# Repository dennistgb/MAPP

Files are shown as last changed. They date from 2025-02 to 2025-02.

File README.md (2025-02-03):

# Testing examples

You can test examples using the [htrun](https://github.com/ARMmbed/mbed-os-tools/tree/master/packages/mbed-host-tests) tool and templated print log.

To run the test, use this command after you build the example:

```
$ mbedhtrun -d <MOUNT_POINT> -p <SERIAL_PORT> -m <TARGET> -f ./BUILD/<TARGET>/<TOOLCHAIN>/mbed-os-example-blinky-baremetal.bin --compare-log tests/blinky-baremetal.log
```

For example:

```
mbedhtrun -d /Volumes/DAPLINK -p /dev/tty.usbmodem21102 -m K64F -f ./BUILD/K64F/GCC_ARM/mbed-os-example-blinky-baremetal.bin --compare-log tests/blinky-baremetal.log
```

To find your target `MOUNT_POINT` and `SERIAL_PORT`, please see [mbedls](https://github.com/ARMmbed/mbed-os-tools/blob/master/packages/mbed-ls/README.md#mbed-ls).

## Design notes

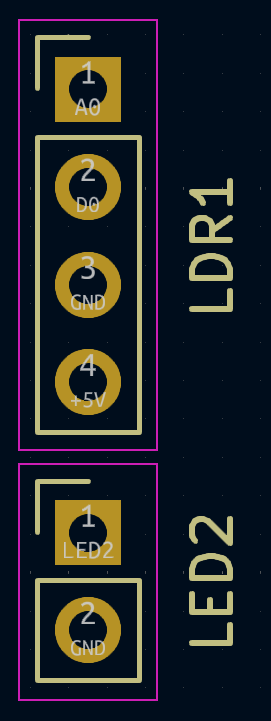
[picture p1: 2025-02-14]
images/pic2.png

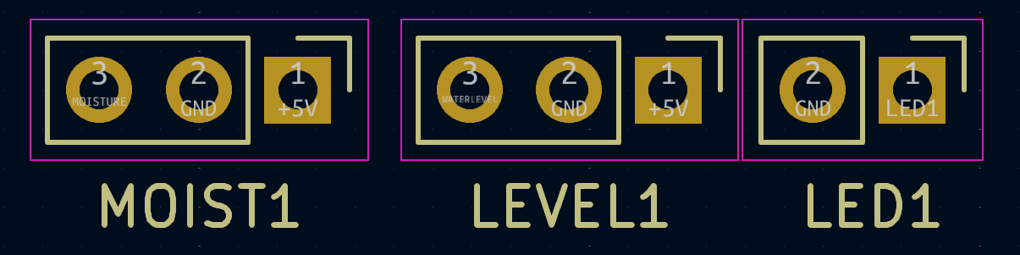
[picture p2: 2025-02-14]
images/pic1.png

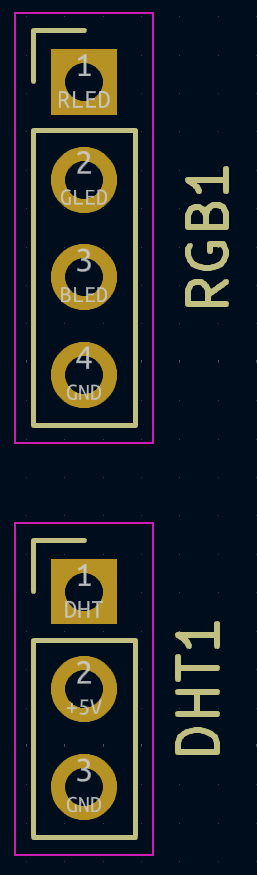
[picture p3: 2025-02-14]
images/pic3.png

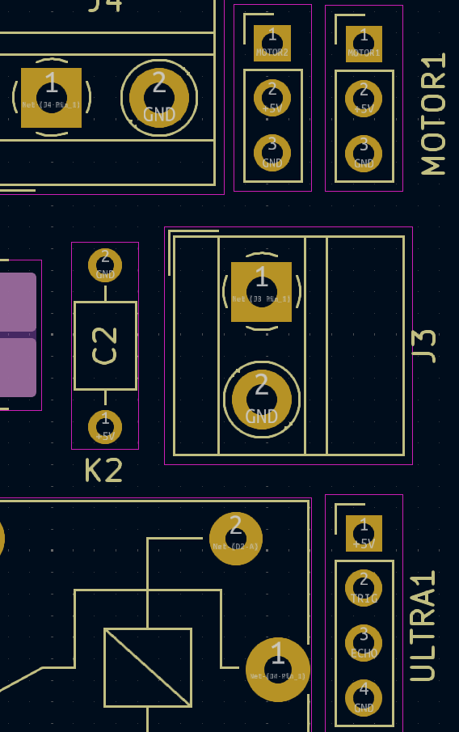
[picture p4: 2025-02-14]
images/pic4.png

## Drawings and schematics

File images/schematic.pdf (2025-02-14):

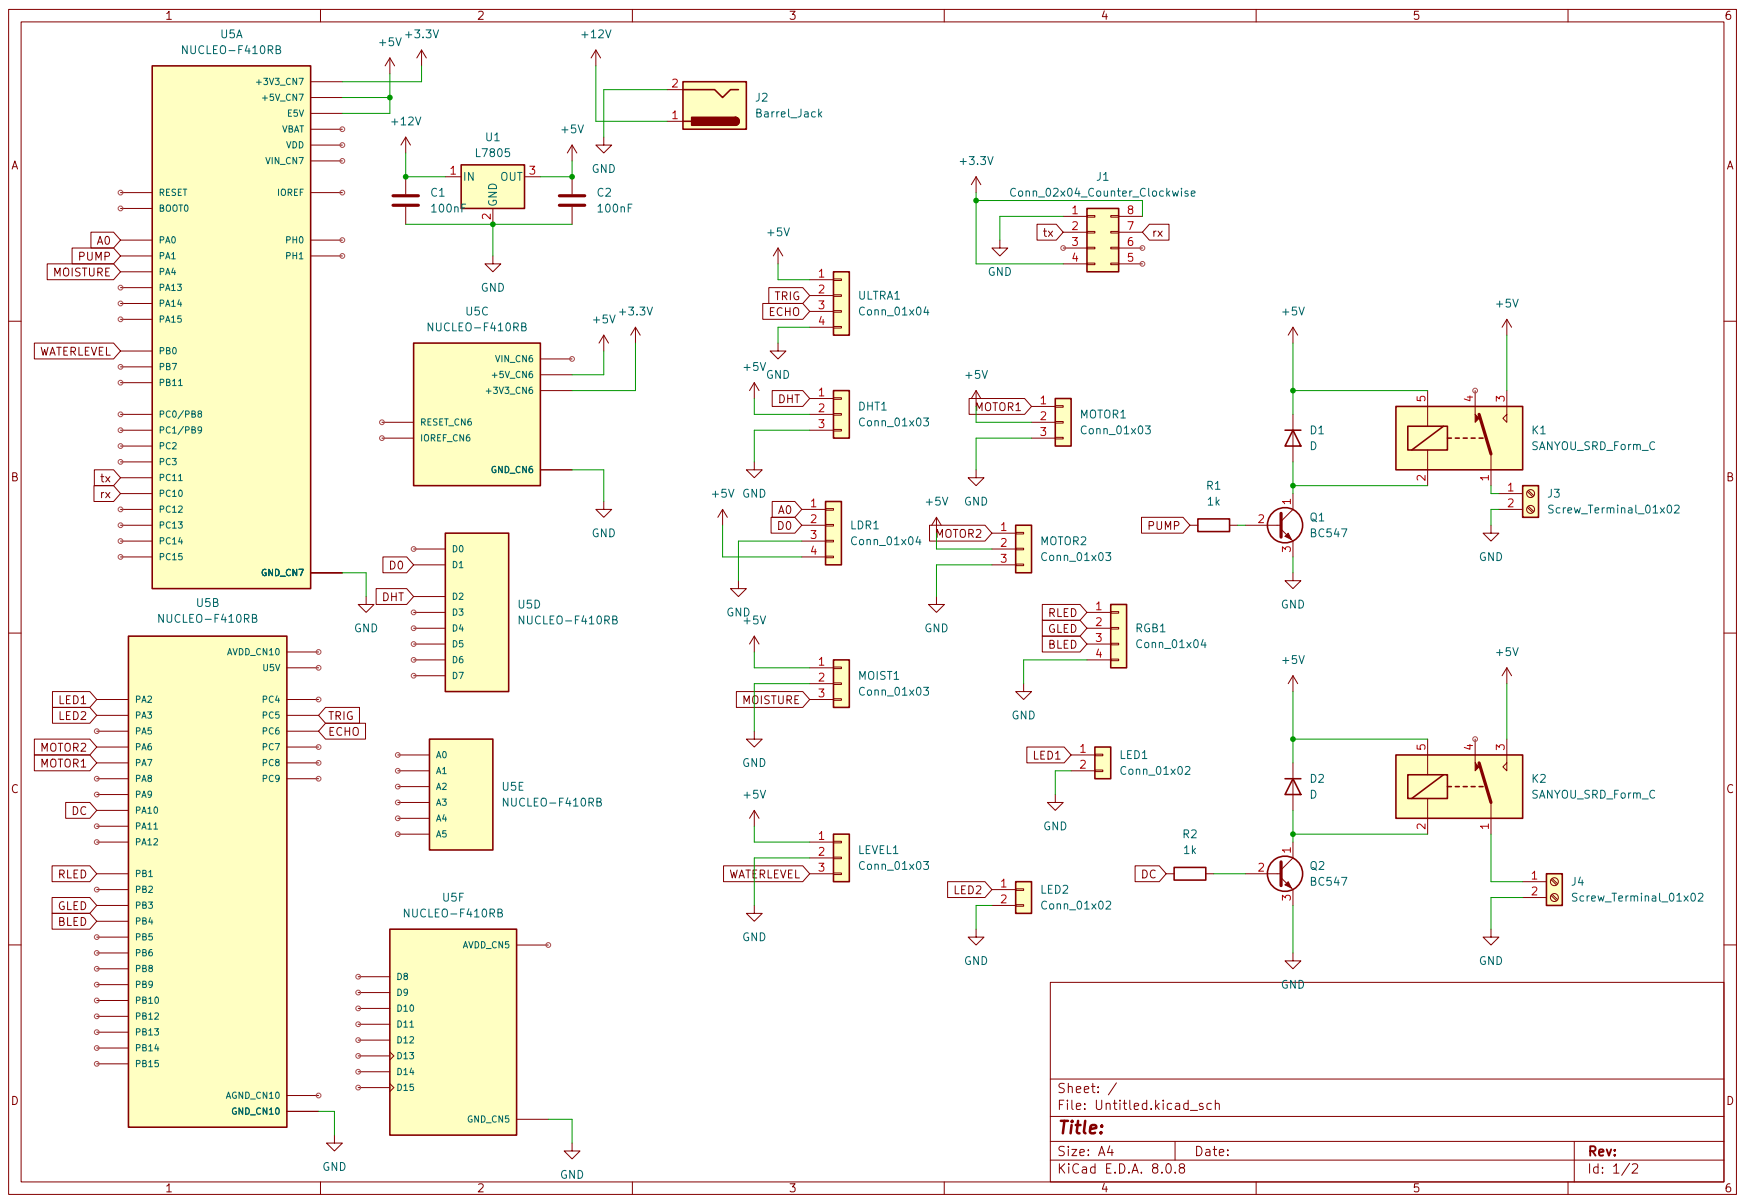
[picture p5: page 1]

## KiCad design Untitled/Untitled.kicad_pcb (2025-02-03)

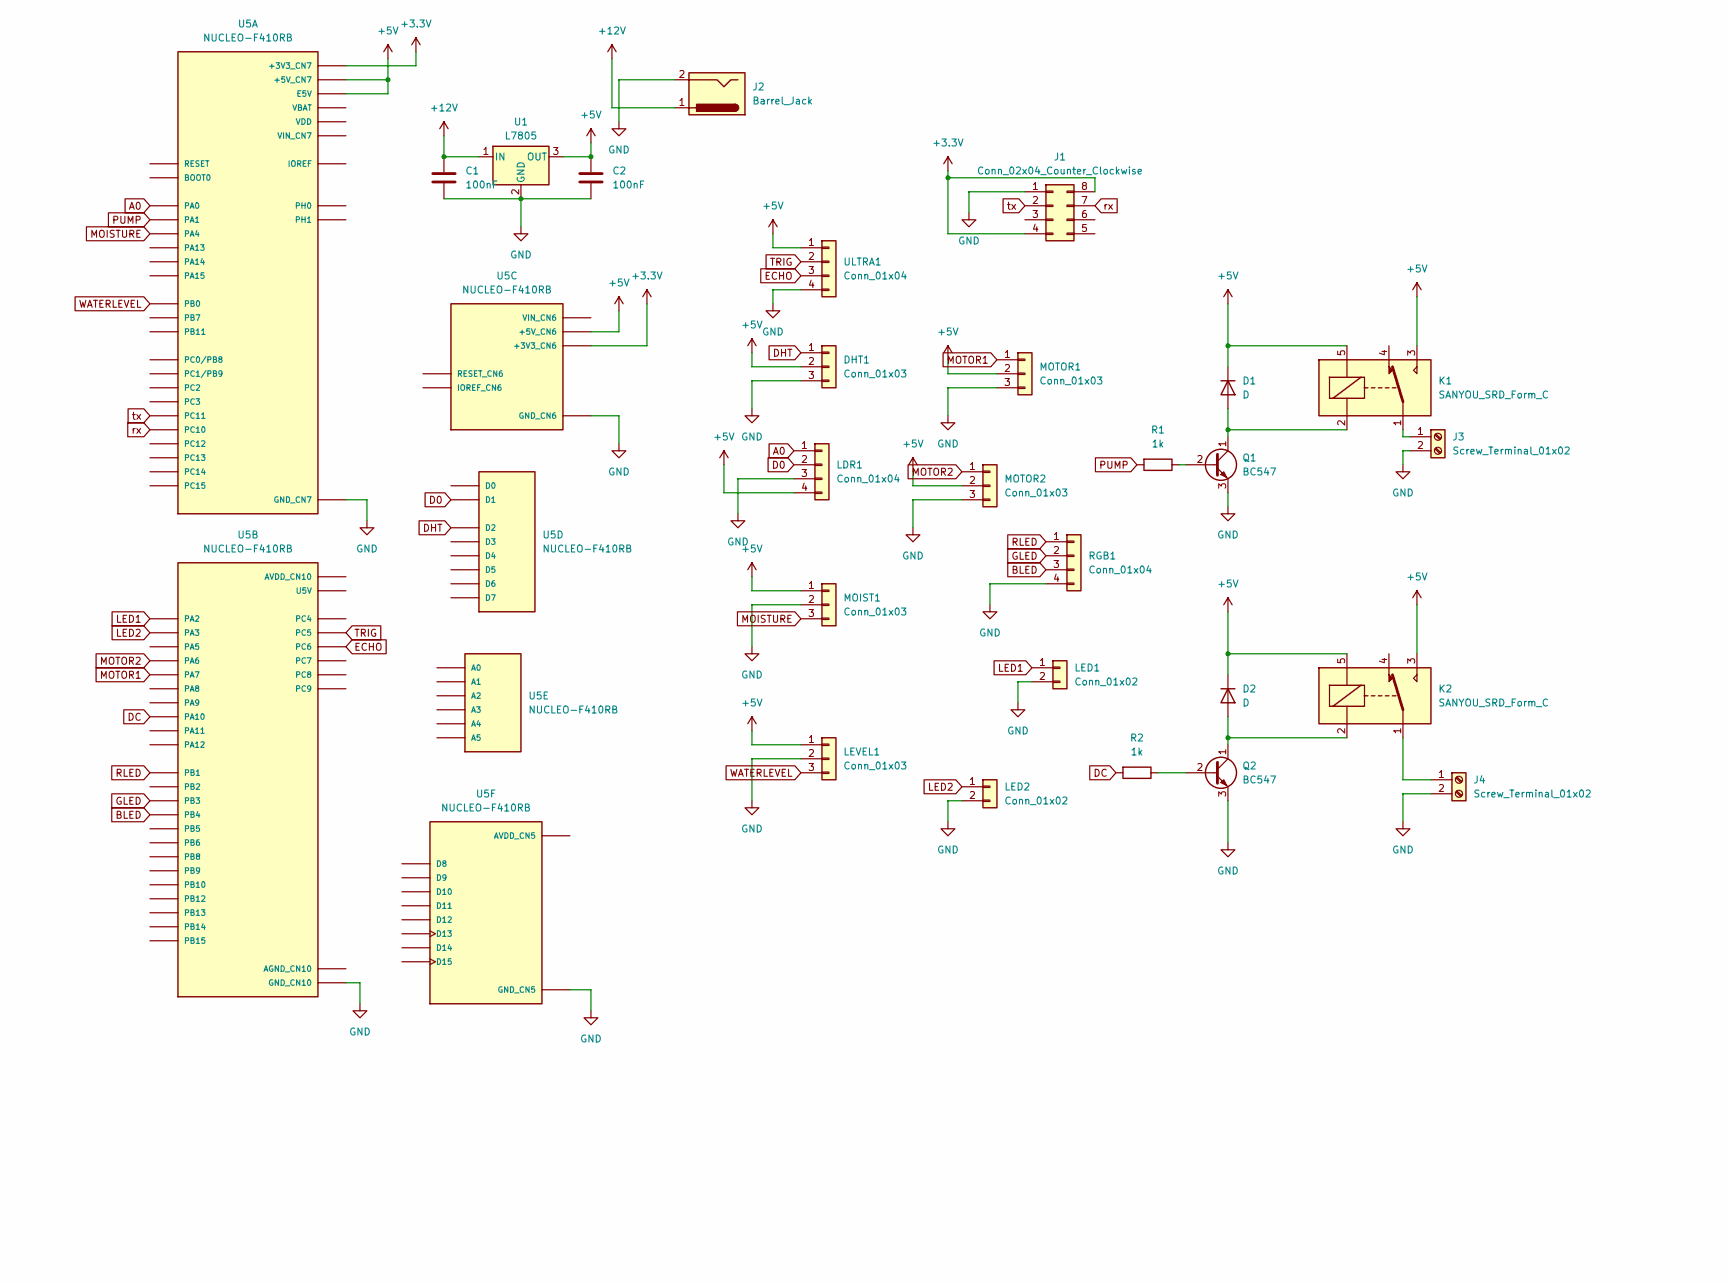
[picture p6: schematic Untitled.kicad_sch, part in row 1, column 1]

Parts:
C1, C2: 100nF; C_Axial_L3.8mm_D2.6mm_P7.50mm_Horizontal
D1, D2: D; D_A-405_P10.16mm_Horizontal
DHT1: Conn_01x03; PinHeader_1x03_P2.54mm_Vertical
J1: Conn_02x04_Counter_Clockwise; PinHeader_2x04_P2.54mm_Vertical
J2: Barrel_Jack; BarrelJack_Kycon_KLDX-0202-xC_Horizontal
J3, J4: Screw_Terminal_01x02; TerminalBlock_MetzConnect_Type011_RT05502HBWC_1x02_P5.00mm_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
K1, K2: SANYOU_SRD_Form_C; Relay_SPDT_SANYOU_SRD_Series_Form_C
LDR1: Conn_01x04; PinHeader_1x04_P2.54mm_Vertical
LED1, LED2: Conn_01x02; PinHeader_1x02_P2.54mm_Vertical
LEVEL1: Conn_01x03; PinHeader_1x03_P2.54mm_Vertical
MOIST1: Conn_01x03; PinHeader_1x03_P2.54mm_Vertical
MOTOR1, MOTOR2: Conn_01x03; PinHeader_1x03_P2.54mm_Vertical
Q1, Q2: BC547; TO-92_Inline
R1, R2: 1k; R_Axial_DIN0207_L6.3mm_D2.5mm_P10.16mm_Horizontal
RGB1: Conn_01x04; PinHeader_1x04_P2.54mm_Vertical
U1: L7805; TO-252-2
U5: NUCLEO-F410RB; ST_NUCLEO-F410RB; PARTREV 13
ULTRA1: Conn_01x04; PinHeader_1x04_P2.54mm_Vertical

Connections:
+3.3V: J1.4, J1.8, U5.CN6_4 (+3V3_CN6), U5.CN7_16 (+3V3_CN7)
+5V: C2.1, D1.1 (K), D2.1 (K), DHT1.2, K1.3, K1.5, K2.3, K2.5, LDR1.4, LEVEL1.1, MOIST1.1, MOTOR1.2, MOTOR2.2, U1.3 (OUT), U5.CN6_5 (+5V_CN6), U5.CN7_6 (E5V), U5.CN7_18 (+5V_CN7), ULTRA1.1
+12V: C1.1, J2.1, U1.1 (IN)
A0: LDR1.1, U5.CN7_28 (PA0)
BLED: RGB1.3, U5.CN10_27 (PB4)
D0: LDR1.2, U5.CN9_2 (D1)
DC: R2.2, U5.CN10_33 (PA10)
DHT: DHT1.1, U5.CN9_3 (D2)
ECHO: U5.CN10_4 (PC6), ULTRA1.3
GLED: RGB1.2, U5.CN10_31 (PB3)
GND: C1.2, C2.2, DHT1.3, J1.1, J2.2, J3.2, J4.2, LDR1.3, LED1.2, LED2.2, LEVEL1.2, MOIST1.2, MOTOR1.3, MOTOR2.3, Q1.3 (E), Q2.3 (E), RGB1.4, U1.2 (GND), U5.CN5_7 (GND_CN5), U5.CN6_6 (GND_CN6), U5.CN6_7 (GND_CN6), U5.CN7_8 (GND_CN7), U5.CN7_19 (GND_CN7), U5.CN7_20 (GND_CN7), U5.CN7_22 (GND_CN7), U5.CN10_9 (GND_CN10), U5.CN10_20 (GND_CN10), ULTRA1.4
LED1: LED1.1, U5.CN10_35 (PA2)
LED2: LED2.1, U5.CN10_37 (PA3)
MOISTURE: MOIST1.3, U5.CN7_32 (PA4)
MOTOR1: MOTOR1.1, U5.CN10_15 (PA7)
MOTOR2: MOTOR2.1, U5.CN10_13 (PA6)
unnamed: D1.2 (A), K1.2, Q1.1 (C)
unnamed: D2.2 (A), K2.2, Q2.1 (C)
unnamed: J3.1, K1.1
unnamed: J4.1, K2.1
unnamed: Q1.2 (B), R1.1
unnamed: Q2.2 (B), R2.1
PUMP: R1.2, U5.CN7_30 (PA1)
RLED: RGB1.1, U5.CN10_24 (PB1)
TRIG: U5.CN10_6 (PC5), ULTRA1.2
WATERLEVEL: LEVEL1.3, U5.CN7_34 (PB0)
rx: J1.7, U5.CN7_1 (PC10)
tx: J1.2, U5.CN7_2 (PC11)

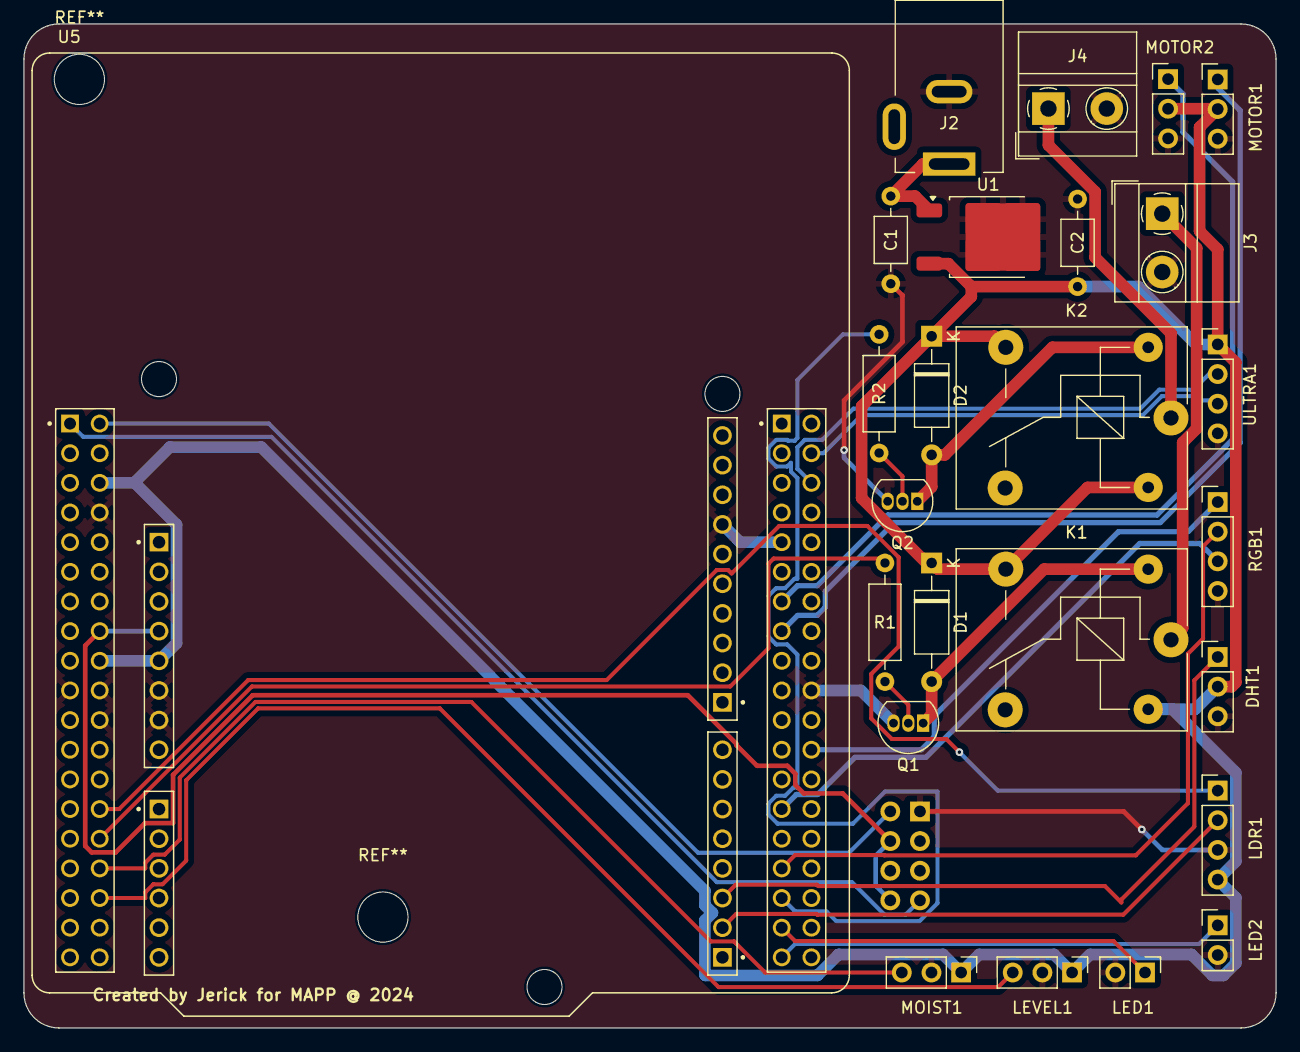
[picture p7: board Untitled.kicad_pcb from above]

Board: 2 copper layers, 107.2 x 86.0 mm, 26 parts (1 on the bottom side), 28 nets.

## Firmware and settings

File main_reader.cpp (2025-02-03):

#include <cstdio>
#undef __ARM_FP
#include "mbed.h"
#include "DHT11.h"
#include <chrono>
using namespace std::chrono;

#define WAIT_TIME_MS_0 500
#define WAIT_TIME_MS_1 1500
// Timeout duration for no object detection
#define ECHO_TIME_OUT 30ms
//Timer for fish feeder
#define INTERVAL 10
//defitions for fish feeder
#define WAIT_TIME_MS 2000          // Sleep time to allow motor to turn
#define PERIOD_WIDTH 20            // Period in ms according to the servo motor datasheet
#define PULSE_WIDTH_90_DEGREE 2400 // Pulse width in us to move to 90 degree position
#define PULSE_WIDTH_0_DEGREE 1500  // Pulse width in us to move to 0 position
#define PULSE_WIDTH_N_90_DEGREE 600 // Pulse width in us to move to -90 degree position

//Grow light Pin
DigitalOut GrowLight(PA_2);

//Warning system (RGB LED) pins
DigitalOut redPin(PB_1);      
DigitalOut greenPin(PB_3); 
DigitalOut bluePin(PB_4); 

// moisture sensor analog pin 
AnalogIn MoistureSensor(PA_4);

//relay to control water pump
DigitalOut relay(PA_1);     

// water level analog pin
AnalogIn water_level(PB_0); 
DigitalIn LDRSensor_DO(PD_1);
AnalogIn LDRSensor_AO(PA_0);

//ultrasound pins
DigitalOut Trig(PC_5);   // Trigger Pin
InterruptIn Echo(PC_6);  // Echo Pin with interrupt
//timers for utlrasound
Timer echoTimer;         // Timer to measure duration
Timeout echoTimeout;     // Timeout handler

// servo motor pins for fish feeder
PwmOut motor(PA_7);
//ticker for fish feeder
Ticker feederTicker;
Timer feederTimer;

//dht pin
DHT11 dht11(PD_2);

float Moist = 0;
float Water_level = 0;
float objDistance = 0;
bool bObjDetected = false;
float LDR_AO_voltage = 0.0;

// ISR for Echo timeout
void ISR_EchoTimeout() 
{
    printf("Timeout: No obstacle detected!\n");
}
// ISR for rising edge (start of Echo signal)
void ISR_EchoHigh()
{
    echoTimer.reset();
    echoTimeout.attach(&ISR_EchoTimeout, ECHO_TIME_OUT);  // Attach timeout handler
}
// ISR for falling edge (end of Echo signal)
void ISR_EchoLow() 
{
    bObjDetected = true;
    echoTimeout.detach();  // Cancel timeout
    float duration = duration_cast<microseconds>(echoTimer.elapsed_time()).count();
    objDistance = (0.03432 * duration) / 2;  // Calculate distance in cm
}

// Function to measure distance using the ultrasonic sensor
float get_distance()
{
    // Send a 10us pulse to the Trigger pin
    Trig = 1;
    wait_us(10);
    Trig = 0;

    // Wait for Echo response
    echoTimer.start();
    while (!Echo.read())  // Wait for rising edge
    {
        if (echoTimer.elapsed_time() > ECHO_TIME_OUT)
        {
            echoTimer.stop();
            echoTimer.reset();
            return -1;  // Timeout, no object detected
        }
    }

    echoTimer.reset();
    echoTimer.start();
    while (Echo.read())  // Wait for falling edge
    {
        if (echoTimer.elapsed_time() > ECHO_TIME_OUT)
        {
            echoTimer.stop();
            echoTimer.reset();
            return -1;  // Timeout, no object detected
        }
    }

    echoTimer.stop();
    float duration = duration_cast<microseconds>(echoTimer.elapsed_time()).count();
    return (0.03432 * duration) / 2;  // Calculate distance in cm
}

// Function to get the temperature using DHT
int get_temp()
{
    int temperature = dht11.readTemperature();
    if (temperature != DHT11::ERROR_CHECKSUM && temperature != DHT11::ERROR_TIMEOUT)
    {
        return temperature; 
    }
    else
    {
        printf("%s\n", dht11.getErrorString(temperature)); 
        return -1; 
    }
}

// Function to get the humidity using DHT
int get_humidity()
{
    int humidity = dht11.readHumidity();
    if (humidity != DHT11::ERROR_CHECKSUM && humidity != DHT11::ERROR_TIMEOUT)
    {
        return humidity; 
    }
    else
    {
        printf("%s\n", dht11.getErrorString(humidity)); 
        return -1; 
    }
}

//Function to get brightness using LDR
int get_brightness()
{
    LDR_AO_voltage = LDRSensor_AO.read();
    LDR_AO_voltage = LDR_AO_voltage * 3.3;
    return LDR_AO_voltage;
}

void pump_water()
{
    relay = 1;
    thread_sleep_for(5000);
    relay = 0;
}

void start_feeder()
{
    motor.period_ms(PERIOD_WIDTH);                   // Set the period according to the servo specification
    motor.pulsewidth_us(PULSE_WIDTH_0_DEGREE);       // Move to 0 position (middle)
    printf("Move to 0 position: Middle\n");

    feederTimer.reset();  // Reset the timer
    feederTimer.start();  // Start the timer
    while (feederTimer.elapsed_time() < std::chrono::milliseconds(WAIT_TIME_MS)) // Wait until the time elapses
    {
        // Optionally, you can add other code here to do something during the waiting time
    }

    motor.pulsewidth_us(PULSE_WIDTH_90_DEGREE);      // Move to 90 degree (right)
    printf("Move to 90 degree position: Right\n");

    feederTimer.reset();  // Reset the timer for the next wait period
    feederTimer.start();  // Start the timer
    while (feederTimer.elapsed_time() < std::chrono::milliseconds(WAIT_TIME_MS)) // Wait until the time elapses
    {
        // Optionally, you can add other code here to do something during the waiting time
    }

    motor.pulsewidth_us(PULSE_WIDTH_N_90_DEGREE);    // Move to -90 degree (left)
    printf("Move to -90 degree position: Left\n");

    feederTimer.reset();  // Reset the timer for the next wait period
    feederTimer.start();  // Start the timer
    while (feederTimer.elapsed_time() < std::chrono::milliseconds(WAIT_TIME_MS)) // Wait until the time elapses
    {
        // Optionally, you can add other code here to do something during the waiting time
    }

    motor.period_ms(PERIOD_WIDTH);                   // Set the period according to the servo specification
}

int main()
{
    LDRSensor_AO.set_reference_voltage(3.3f);
    feederTicker.attach(&start_feeder, INTERVAL);
    
    while (1)
    {
        printf("Reading phase\n");
        // Temperature reading
        int temperature = get_temp();
        if (temperature != -1)
        {
            printf("Temperature: %d °C\n", temperature);
        }
        else
        {
            printf("Failed to read temperature.\n");
        }

        // Humidity reading
        int humidity = get_humidity();
        if (humidity != -1)
        {
            printf("Humidity: %d %%\n", humidity);
        }
        else
        {
            printf("Failed to read humidity.\n");
        }

        // Distance reading
        float distance = get_distance();
        if (distance != -1)
        {
            printf("Distance: %.2f cm\n", distance);
        }
        else
        {
            printf("Failed to detect distance.\n");
        }

        //brightness reading
        float brightness = get_brightness();
        printf("Brightness: %.3f V\n", brightness);

        Moist = MoistureSensor.read(); 
        printf("Soil Moisture: %.2f\n", Moist);
        
        Water_level = water_level.read(); 
        printf("Water Level: %.2f\n", Water_level);

        thread_sleep_for(1000);

        printf("Correctional phase\n");
        if (temperature == 50)
        {
            //start dc motor fan
        }
        if (humidity == 60)
        {
            //start dc motor fan
        }
        //If plant is too close (needs to be cut) put red on RGB LED
        if(distance == 10)
        {
            bluePin = 0;
            greenPin = 0;
            redPin = 1;
        }
        else 
        {
            bluePin = 0;
            greenPin = 1;
            redPin = 0;
        }
        //If brightness is too low turn on grow light
        if (brightness > 2.2)
        {
            GrowLight = 1;
        }
        else 
        {
            GrowLight = 0;
        }
        //If soil moisture too low pump water
        if (Moist == 0.95) 
        {
            pump_water();
        }
        //If water level to high, put up blue warning LED
        if (Water_level == 10)
        {
            bluePin = 1;
            greenPin = 0;
            redPin = 0;
        }
        else 
        {
            bluePin = 0;
            greenPin = 1;
            redPin = 0;
        }
    }
}

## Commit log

2025-02-02 added kicad thing
    [Untitled.kicad_pcb, Untitled.kicad_sch, mcu2.kicad_sch]
2025-02-02 started work on thing
    [Untitled.kicad_pcb, Untitled.kicad_sch, mcu2.kicad_sch]
